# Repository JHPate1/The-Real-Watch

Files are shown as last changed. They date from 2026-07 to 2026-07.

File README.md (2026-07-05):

 # The-Real-Watch
> A watch that ACTUALLY tracks your health by monitoring your surroundings and constantly monitoring for active threats.

---

## What is it and how is it different??

Let me start from the drawing board. I've noticed EXPENSIVE Garmin, Apple and Fitbits that don't even do their real job. Like for example, your health isn't just your BPM, O2 and Pedometer levels. It's more than that. My watch includes ALL those AND a environmental sensor, because the real influencing force is the environment you're in, not how much you walk. This watch constantly scans for CO2, Gas, Noise, Pressure, Noise levels and more! This watch is also capable of running APPs that runs via bluetooth and wifi. It can be used to communicate with other watches eg; if you're hiking and your friend has the same watch. You can communicate with them in realtime like a walkie talkie. This watch isnt just any watch, Its a watch that breaks feats that were never imaginable. Imagine being able to view your bank balance all from your watch that has a ESP32 inside of it!
This is indeed a very ambitious venture but I AM confident I have what it takes.

---

## BOM

*(Tarrifs are gonna kill this project, smh)*

| Item | Cost |
|---|---|
| PCB + 3D Printing (PCBWay, Cheaper than JLCPCB) | $157.90 |
| PCBWay Balance | -$25.00 |
| Coupons | -$8.00 |
| 3D printing | -$24.90 |
| **PCBWay Total** | **$100.00** |
| | |
| 8 Ohm Small Speakers | $8.45 |
| Mini Vibration Motors | $5.99 |
| 3.7V 500mAh 603030 Lipo Battery Rechargeable Lithium Polymer ion Battery Pack | $6.99 |
| waveshare 1.28inch Round LCD Display Module with Touch Panel | $25.99 |
| Amazon Tax | $2.52 |
| **Amazon Total** | **$49.94** |
| | |
| **Project TOTAL** | **$149.94** |

> **Tariffs and shipping are likely to be decided later, or the prices may go down.**

---

## What about the software?

The software is already in development! I am making the internal code first as I dont know how the screen will behave.

---

## Pictures




(Render by my friend in blender, does not have github so I will update this Readme once he does.)

(Yes I use tinkercad, so what? My laptop doesn't even run cloud services like onshape efficiently, and this was before I was notified of the deadline extension.)

## Special thanks

Outpost by HackClub! (Bro this is my 40th project im submitting, this time with EVERYTHING. I've worked 30 HOURS and MY MENTAL HEALTH off of this project, so PLEASE approve this for funding. I even selected the CHEAPEST components for this project, the tarrifs aren't even my fault)

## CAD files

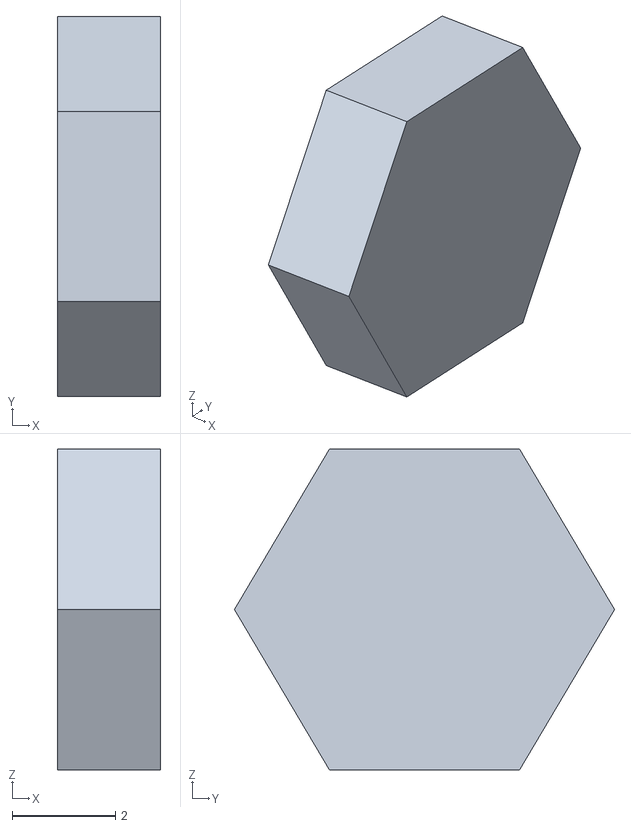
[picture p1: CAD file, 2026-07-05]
CAD/D.stl
2.00 x 7.36 x 6.22

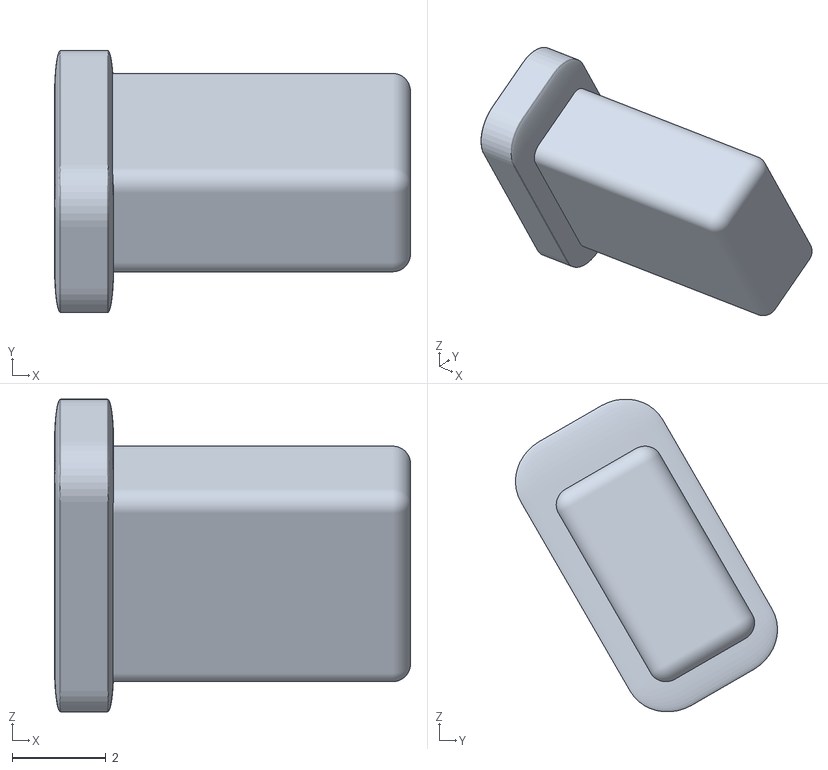
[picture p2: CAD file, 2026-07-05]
CAD/C.stl
7.60 x 5.59 x 6.67

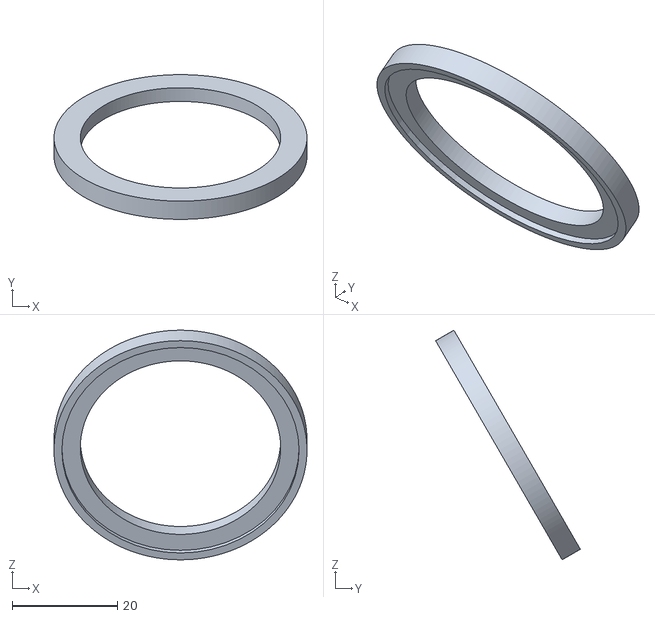
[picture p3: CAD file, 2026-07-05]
CAD/E.stl
48.0 x 27.5 x 43.6

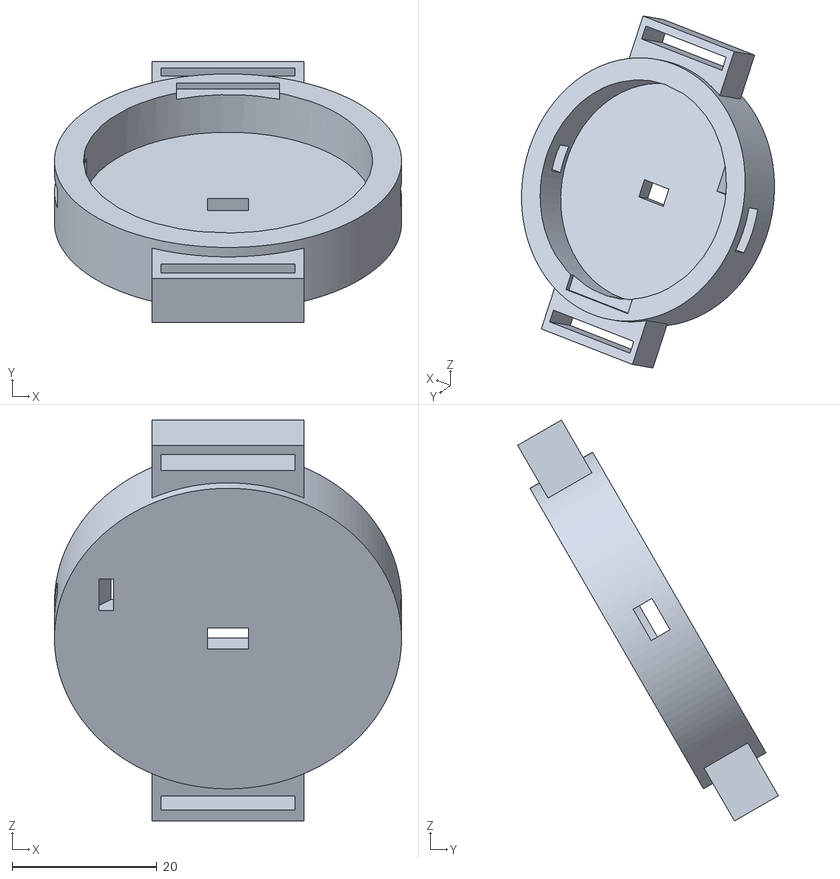
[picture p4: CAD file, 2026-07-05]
CAD/B.stl
48.0 x 36.1 x 55.5

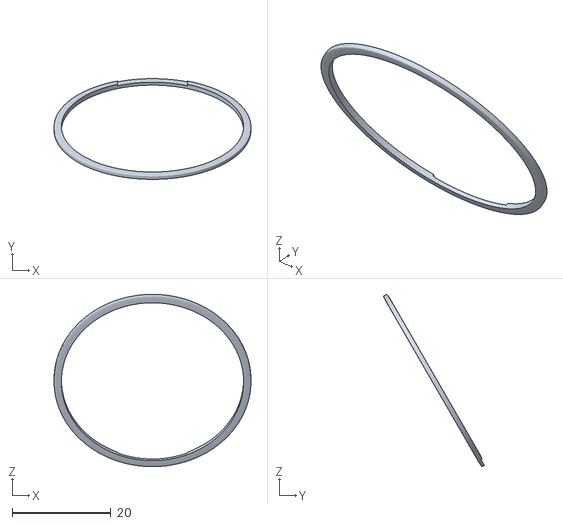
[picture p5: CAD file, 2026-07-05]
CAD/A.stl
40.0 x 20.5 x 35.0

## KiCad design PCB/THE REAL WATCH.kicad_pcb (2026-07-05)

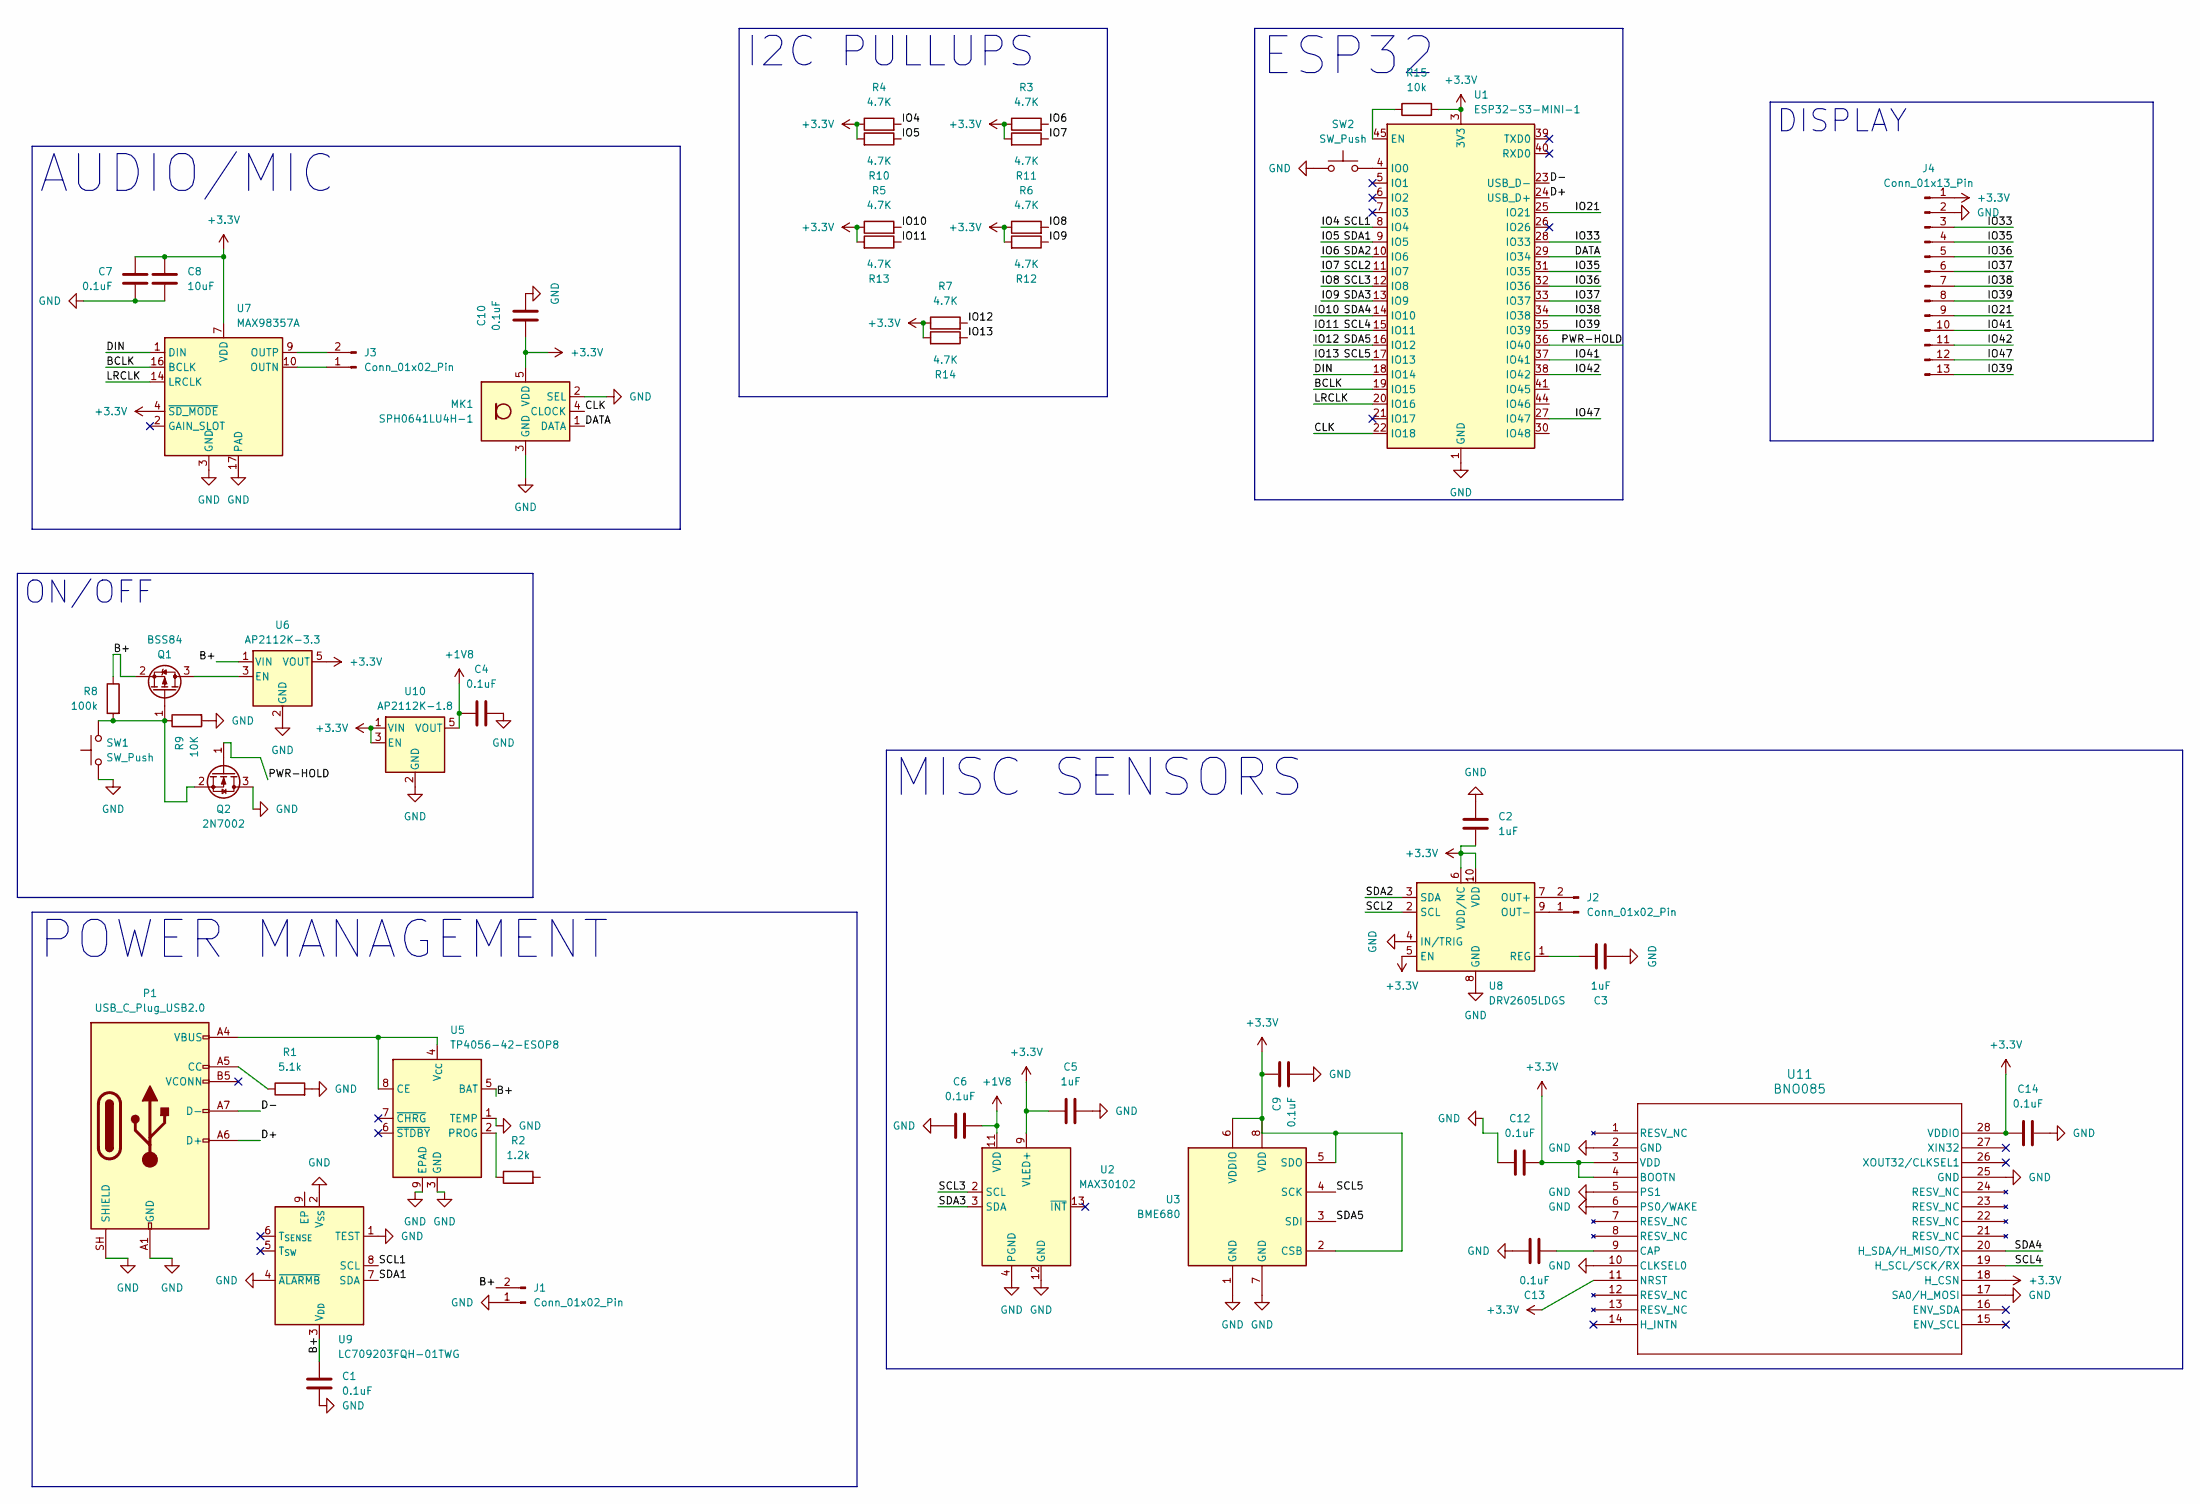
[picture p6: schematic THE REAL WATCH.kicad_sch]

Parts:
C1, C4, C6, C7, C9, C10, C12, C13, C14: 0.1uF; C_0603_1608Metric
C2, C3, C5: 1uF; C_0603_1608Metric
C8: 10uF; C_0603_1608Metric
J1, J2, J3: Conn_01x02_Pin; PinHeader_1x02_P1.00mm_Vertical
J4: Conn_01x13_Pin; PinHeader_1x13_P1.00mm_Vertical
MK1: SPH0641LU4H-1; Knowles_LGA-5_3.5x2.65mm
P1: USB_C_Plug_USB2.0; USB_C_Receptacle_Amphenol_124019772112A
Q1: BSS84; SOT-23
Q2: 2N7002; SOT-23
R1: 5.1k; R_0603_1608Metric
R2: 1.2k; R_0603_1608Metric
R3, R4, R5, R6, R7, R10, R11, R12, R13, R14: 4.7K; R_0603_1608Metric
R8: 100k; R_0603_1608Metric
R9: 10K; R_0603_1608Metric
R15: 10k; R_0603_1608Metric
SW1: SW_Push; Panasonic_EVQPUJ_EVQPUA
SW2: SW_Push; SW_Push_1P1T_NO_CK_KMR2
U1: ESP32-S3-MINI-1; ESP32-S2-MINI-1
U2: MAX30102; Maxim_OLGA-14_3.3x5.6mm_P0.8mm
U3: BME680; Bosch_LGA-8_3x3mm_P0.8mm_ClockwisePinNumbering
U5: TP4056-42-ESOP8; WSON-14-1EP_4.0x4.0mm_P0.5mm_EP2.6x2.6mm
U6: AP2112K-3.3; SOT-23-5
U7: MAX98357A; TQFN-16-1EP_3x3mm_P0.5mm_EP1.23x1.23mm
U8: DRV2605LDGS; TSSOP-10_3x3mm_P0.5mm
U9: LC709203FQH-01TWG; WDFN-8-1EP_4x3mm_P0.65mm_EP2.4x1.8mm
U10: AP2112K-1.8; SOT-23-5
U11: BNO085; LGA-28_CEV

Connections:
+1V8: C4.1, C6.1, U2.11 (VDD), U10.5 (VOUT)
+3.3V: C2.2, C5.2, C7.1, C8.1, C9.1, C10.1, C12.1, C14.1, J4.1, MK1.5 (VDD), R3.1, R4.1, R5.1, R6.1, R7.1, R10.2, R11.2, R12.2, R13.2, R14.2, R15.2, U1.3 (3V3), U2.9 (VLED+), U2.10 (VLED+), U3.2 (CSB), U3.5 (SDO), U3.6 (VDDIO), U3.8 (VDD), U6.5 (VOUT), U7.4 (~SD_MODE), U7.7 (VDD), U7.8 (VDD), U8.5 (EN), U8.6 (VDD/NC), U8.10 (VDD), U10.1 (VIN), U10.3 (EN), U11.3 (VDD), U11.4 (BOOTN), U11.11 (NRST), U11.18 (H_CSN), U11.28 (VDDIO)
/B+: C1.1, J1.2, Q1.2 (S), R8.1, U5.5 (BAT), U6.1 (VIN), U9.3 (V_{DD})
/BCLK: U1.19 (IO15), U7.16 (BCLK)
/CLK: MK1.4 (CLOCK), U1.22 (IO18)
/D+: P1.A6 (D+), U1.24 (USB_D+)
/D-: P1.A7 (D-), U1.23 (USB_D-)
/DATA: MK1.1 (DATA), U1.29 (IO34)
/DIN: U1.18 (IO14), U7.1 (DIN)
/IO4: R4.2, U1.8 (IO4), U9.8 (SCL)
/IO5: R10.1, U1.9 (IO5), U9.7 (SDA)
/IO6: R3.2, U1.10 (IO6), U8.3 (SDA)
/IO7: R11.1, U1.11 (IO7), U8.2 (SCL)
/IO8: R6.2, U1.12 (IO8), U2.2 (SCL)
/IO9: R12.1, U1.13 (IO9), U2.3 (SDA)
/IO10: R5.2, U1.14 (IO10), U11.20 (H_SDA/H_MISO/TX)
/IO11: R13.1, U1.15 (IO11), U11.19 (H_SCL/SCK/RX)
/IO12: R7.2, U1.16 (IO12), U3.3 (SDI)
/IO13: R14.1, U1.17 (IO13), U3.4 (SCK)
/IO21: J4.9, U1.25 (IO21)
/IO33: J4.3, U1.28 (IO33)
/IO35: J4.4, U1.31 (IO35)
/IO36: J4.5, U1.32 (IO36)
/IO37: J4.6, U1.33 (IO37)
/IO38: J4.7, U1.34 (IO38)
/IO39: J4.8, J4.13, U1.35 (IO39)
/IO41: J4.10, U1.37 (IO41)
/IO42: J4.11, U1.38 (IO42)
/IO47: J4.12, U1.27 (IO47)
/LRCLK: U1.20 (IO16), U7.14 (LRCLK)
/PWR-HOLD: Q2.1 (G), U1.36 (IO40)
GND: C1.2, C2.1, C3.2, C4.2, C5.1, C6.2, C7.2, C8.2, C9.2, C10.2, C12.2, C13.2, C14.2, J1.1, J4.2, MK1.2 (SEL), MK1.3 (GND), P1.A1 (GND), P1.A12 (GND), P1.B1 (GND), P1.B12 (GND), P1.SH (SHIELD), Q2.3 (D), R1.2, R9.2, SW1.1, SW2.1, U1.1 (GND), U1.2 (GND), U1.42 (GND), U1.43 (GND), U1.46 (GND), U1.47 (GND), U1.48 (GND), U1.49 (GND), U1.50 (GND), U1.51 (GND), U1.52 (GND), U1.53 (GND), U1.54 (GND), U1.55 (GND), U1.56 (GND), U1.57 (GND), U1.58 (GND), U1.59 (GND), U1.60 (GND), U1.61 (GND), U1.62 (GND), U1.63 (GND), U1.64 (GND), U1.65 (GND), U2.4 (PGND), U2.12 (GND), U3.1 (GND), U3.7 (GND), U5.1 (TEMP), U5.3 (GND), U5.9 (EPAD), U6.2 (GND), U7.3 (GND), U7.11 (GND), U7.15 (GND), U7.17 (PAD), U8.4 (IN/TRIG), U8.8 (GND), U9.1 (TEST), U9.2 (V_{SS}), U9.4 (~ALARMB), U10.2 (GND), U11.2 (GND), U11.5 (PS1), U11.6 (PS0/WAKE), U11.10 (CLKSEL0), U11.17 (SA0/H_MOSI), U11.25 (GND)
unnamed: J2.1, U8.9 (OUT-)
unnamed: J2.2, U8.7 (OUT+)
unnamed: J3.1, U7.10 (OUTN)
unnamed: J3.2, U7.9 (OUTP)
unnamed: P1.A5 (CC), R1.1
unnamed: Q1.3 (D), U6.3 (EN)
unnamed: Q1.1 (G), Q2.2 (S), R8.2, R9.1, SW1.2
unnamed: R15.1, U1.45 (EN)
unnamed: SW2.2, U1.4 (IO0)
unnamed: P1.A4 (VBUS), P1.A9 (VBUS), P1.B4 (VBUS), P1.B9 (VBUS), U5.4 (V_{CC}), U5.8 (CE)
unnamed: R2.1, U5.2 (PROG)
unnamed: C3.1, U8.1 (REG)
unnamed: C13.1, U11.9 (CAP)

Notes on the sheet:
DISPLAY
MISC SENSORS
ESP32
I2C PULLUPS
ON/OFF
POWER MANAGEMENT
AUDIO/MIC

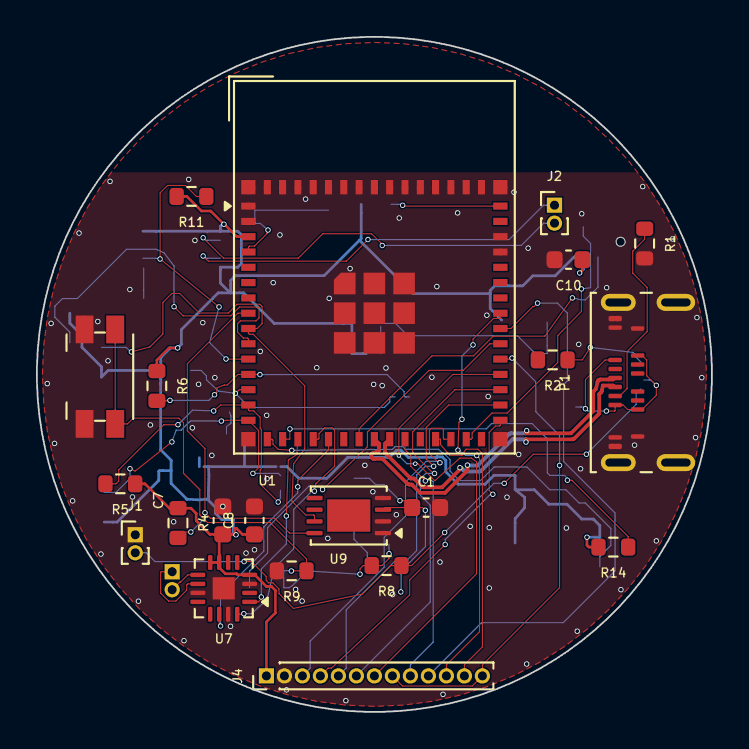
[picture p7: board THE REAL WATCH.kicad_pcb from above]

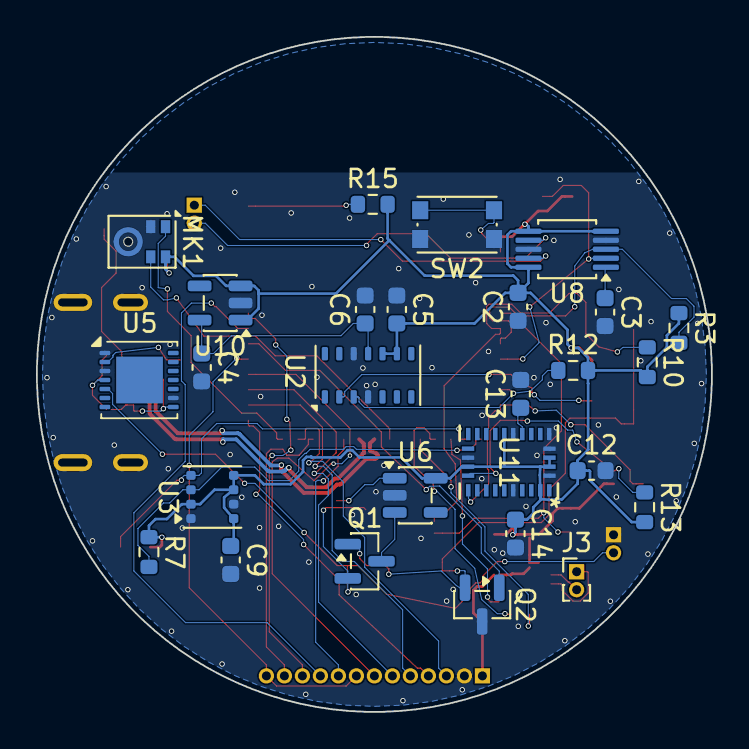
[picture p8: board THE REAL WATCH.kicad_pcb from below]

Board: 2 copper layers, 37.5 x 37.5 mm, 48 parts (27 on the bottom side), 45 nets.

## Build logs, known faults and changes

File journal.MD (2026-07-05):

## Journal here!

So I thought of this cool idea because my brother was getting an Apple Watch and I thought to myself, what are the benefits of an overpriced watch? Nothing! A majority of people don't even use the watch to its full extent.

So I decided to make this project.

I am writing this after making the project with a stopwatch book I logged the hours into. (rounded to the nearest 10)

---

## Log 1

I loaded up the good old KiCad and laid every footprint I needed out. Then I pulled out my trusty old wiring tool and got to work. Obviously this was a basic rough outline without caps and resistors. I've done enough failed projects to know how to wire things at this point. It took me a solid 50 minutes to do everything.

**Time: 50 minutes**

---

## Log 2

I started reading datasheets and adding components 1 by 1. This took me a lot of time so I split this up into 2 logs. I looked through the power management, and the charging.

**Time: 2.30 hours**

---

## Log 3

After a night's rest I started again. I read and implemented the rest. It was really simple because they were just I2C components that needed decoupling caps and pull-up resistors.

**Time: 40 mins**

---

## Log 4

Well. There's the schematic. Done. I proceeded to go to Onshape like many have suggested and start designing. WOW it's great. But my old hunk of a laptop refused to have a smooth connection and the drops got to a point where I needed to switch to Tinkercad.

**Time: 7 hours gone..**

---

## Log 5

I was looking for a CMF watch vibe so I laid out the main base enclosure and threw a little plastic piece that sits as a bezel on top of the screen to keep it premium. Also while trying to calculate space which LUCKILY I did this case before the routing.

**Time: 3 hours**

---

## Log 6, 7, 8, 9, 10

Yes I took quite a lot of breaks because THIS was the hardest thing I've done.

With the space of a peanut I needed to implement ALL of this onto a 2 layer PCB. Thank god I took breaks.

I routed the USB differentials first then the rest. Surprisingly blindly routing everything then adjusting trace widths saved some time but I obviously needed to restart from scratch 9 times because of some traces that blocked other traces. It's like a puzzle. You need to find the order of things which are placed before you can place things.

**Time: 15 HOURS :skull:**

### Total, 29 Hours

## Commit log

2026-07-05 Enhance README with project overview and BOM
    Expanded the README to include project details, BOM, software status, and images.
2026-07-05 Rename THE REAL WATCH.zip to Gerber.zip
